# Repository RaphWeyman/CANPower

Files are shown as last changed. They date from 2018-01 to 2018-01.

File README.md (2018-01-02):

# CANPower
Accessory power controller for BMW CAN bus bikes

Two channel power switch using BMW CAN bus messages to control switch output.
Microchip PIC24 based.

Hardware is a printed circuit board created and modifiable with KiCAD. If no modifications are required then the gerbers zip file
can be used as is to get manufactured. The gerber file names are as required by Elecrow.

The software is packaged as a Microchip PIC IDE project and requires Microchip MPLAB X with the 16 bit PIC compiler installed - all free
from the Microchip website.

The 6 way "debug" header on the PCB connects directly to the the Microchip PICKit 3 debugger/programmer. This or some other programmer is
required in order to program the software to the Microchip MCU.

Functionality may easily be changed by modifying the application.c file.
Here's what the default application does:-
 * Switch channel 1 is set to go fully on or fully off with the ignition for accessory power
 * (can easily be changed to staying off by changing the CHANNEL_1_ON define).
 * 
 * Channel 0 is controlled by the ASC switch (can be changed with the BUTTON_PRESSED define).
 * Channel 0 has two modes; modulated and unmodulated. Unmodulated behaves like channel 1; fully on
 * or fully off with the ignition.
 * Modulated is PWM controlled for several power levels from fully off to fully on and each of the quarters
 * inbetween (modify at the CHANNEL_0_PWM_SETTING). PWM is slow for heated clothing but can be changed to
 * fast by changing the CHANNEL_0_PWM_MODE.
 * A long press (>20 seconds) of the control button toggles between modulated and unmodulated modes.
 * A short press (<1 second) of the control button while in modulated mode cycles through the modulation levels.
 * Channel 0 mode and modulation level are stored in EEPROM at power off time (immmediately prior to transition to the
 * alarm simulation state)).
 * 
 * An alarm simulation is included after the ignition is turned off (and the POWER_OFF_DELAY has elapsed).
 * During alarm simulation the switch chip is turned off but the LED indicates as if there were an
 * alarm module armed.
 * Alarm simulation continues for the ALARM_SIMULATION_TIME or can be disabled by setting the ALARM_SIMULATION_TIME to zero.
 * A kickstand warning indication is output to the LEDs if the kickstand is deployed while the ignition is on
 * The warning can be disabled by commenting out the KICKSTAND_WARNING define.
 * 
 * Ignition on is determined by CAN messages being received.
 * Fully on state is maintained POWER_OFF_DELAY. If no CAN messages are received for longer than the POWER_OFF_DELAY
 * then channels 0 and 1 are both turned off and the alarm simulation is stated.
 * Power to the CPU is latched using the PORT_POWER hardware control. When either the ignition is on or the PORT_POWER is set to
 * POWER_PORT_ON power is supplied to the CPU. This allows the CPU to maintain power during the POWER_OFF_DELAY
 * and the ALARM_SIMLATION_TIME. At the end of the ALARM_SIMULATION_TIME, the PORT_POWER is set to POWER_PORT_OFF so as to cut
 * power.
 * 
 * Indications are assumed to be for a single bi-colour LED.
 * LED is dimmed according to the ambient light sensor CAN bus message.
 * LED0 fully on indicates channel 0 is in unmodulated mode.
 * LED1 on but with between 1 and 4 inverse blips indicates channel 0 modulated mode and the number of inverse blips indicate
 * the modulation level (4 blips - fully on).
 * LED1 flashes 4 blips when the channel 0 mode is changed.
 * Both LED0 and LED1 fully off indicate either modulated mode with channel 0 output at the fully off level or no power to the CPU.
 * LED0 flashing at 1Hz indicates that the kickstand is extended.
 * LED0 flashing at 4Hz indicates a switch chip fault - recover by ignition off/ignition on.
 * LED1 blips every few seconds for the alarm simulation.
 * Indications can all be changed by modifying the INDICATIONS and CHANNEL_0_INDICATIONS table.
 *
 * Application is a state machine with a single state variable 'state' and a function of type
 * state_function_t for each state.
 * Each state function must implement the actions for state entry and for state maintenance.
 * The current state's function is invoked regularly (once per timer tick).
 * The StateTransition function is used to change state.
 * The state machnine can be extended by adding to BOTH the states_t and the STATE_FUNCTIONS

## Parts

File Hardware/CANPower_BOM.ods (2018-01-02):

Source: | C:/Users/Raph/Documents/KiCad/CANPower/CANPower.sch
Date: | 26/11/2017 18:06:25
Tool: | Eeschema 4.0.7
Component Count: | 62
Ref | Value | Footprint | Manufacturer | Quantity | Vendor | Vendor#
C1 | 20pF | 1206 |  | 2 | Farnell | 1650896
C2 | 20pF | 1206 |  |  | Farnell | 1650896
C3 | 100nF | 1206 |  | 8 | Farnell | 2070498
C4 | 10uF | 1210 |  | 6 | Farnell | 2070524
C5 | 100nF | 1206 |  |  | Farnell | 2070498
C7 | 10uF | 1210 |  |  | Farnell | 2070524
C9 | 10uF | 1210 |  |  | Farnell | 2070524
C10 | 10uF | 1210 |  |  | Farnell | 2070524
C11 | 22nF | 1206 |  | 4 | Farnell | 2070507
C12 | 2u2 | 1210 |  | 3 | Farnell | 2070526
C13 | 2u2 | 1210 |  |  | Farnell | 2070526
C14 | 100nF | 1206 |  |  | Farnell | 2070498
C15 | 100nF | 1206 |  |  | Farnell | 2070498
C16 | 2u2 | 1210 |  |  | Farnell | 2070526
C17 | 10uF | 1210 |  |  | Farnell | 2070524
C18 | 10uF | 1210 |  |  | Farnell | 2070524
C19 | 100nF | 1206 |  |  | Farnell | 2070498
C20 | 100nF | 1206 |  |  | Farnell | 2070498
C21 | 22nF | 1206 |  |  | Farnell | 2070507
C22 | 100nF | 1206 |  |  | Farnell | 2070498
C23 | 22nF | 1206 |  |  | Farnell | 2070507
C24 | 22nF | 1206 |  |  | Farnell | 2070507
C29 | 100nF | 1206 |  |  | Farnell | 2070498
D1 | BAV74LT1G | SOT-23 |  | 1 | Farnell | 2463435
F1 | 2A | 1206 |  | 1 | Farnell | 1841062
J1 | CAN | Solder wires direct
J3 | Debug | 0.1” pitch 6 way pin header
J4 | Power | Solder wires direct
J5 | Output0 | Solder wires direct
J6 | Output1 | Solder wires direct
J7 | BATT | Solder wires direct
J8 | LED | Solder wires direct
L1 | 22uH |  | Coilcraft MSS7341 | 1 | Farnell | 2288672
Q1 | BSS83P | SOT-23 |  | 2 | Farnell | 2432722
Q2 | BSS83P | SOT-23 |  |  | Farnell | 2432722
R1 | 10K | 1206 |  | 2 | Farnell | 2447455
R2 | 1M | 1206 |  | 5 | Farnell | 2447478
R3 | 1M | 1206 |  |  | Farnell | 2447478
R4 | 470K | 1206 |  | 2 | Farnell | 2447519
R5 | 100K | 1206 |  | 4 | Farnell | 2447453
R6 | 52K3 | 1206 |  | 1 | Farnell | 2307751
R7 | 10K | 1206 |  |  | Farnell | 2447455
R8 | 120R | 1206 |  | 1 | Farnell | 2447462
R9 | 100K | 1206 |  |  | Farnell | 2447453
R10 | 100K | 1206 |  |  | Farnell | 2447453
R11 | 1K | 1206 |  | 1 | Farnell | 2447473
R12 | 8K2 | 1206 |  | 2 | Farnell | 2447547
R13 | 100K | 1206 |  |  | Farnell | 2447453
R14 | 8K2 | 1206 |  |  | Farnell | 2447547
R15 | 2K2 | 1206 |  | 1 | Farnell | 2447496
R16 | 150R | 1206 |  | 2 | Farnell | 2447466
R17 | 150R | 1206 |  |  | Farnell | 2447466
R18 | 470K | 1206 |  |  | Farnell | 2447519
R19 | 1M | 1206 |  |  | Farnell | 2447478
R20 | 1M | 1206 |  |  | Farnell | 2447478
R21 | 1M | 1206 |  |  | Farnell | 2447478
U1 | MCP1727-3302 | SOIC-8 | Microchip | 1 | Farnell | 1331497
U2 | MCP16311 | MSOP-8 | Microchip | 1 | Farnell | 2414134
U3 | MCP2562-E/SN | SOIC-8 | Microchip | 1 | Farnell | 2362839
U4 | MC06XSD200 |  | NXP | 1 | Farnell | 2377190
U5 | PIC24HJ128GP504 | TQFP-44 | Microchip | 1 | Farnell | 1576883
Y1 | 4MHz | HC49 | Fox HC49SDLF | 1 | Farnell | 2063966

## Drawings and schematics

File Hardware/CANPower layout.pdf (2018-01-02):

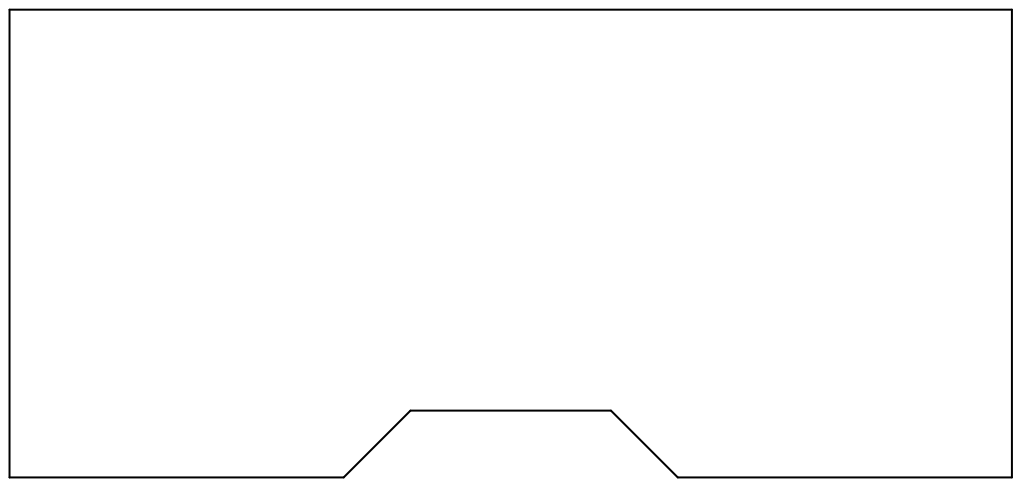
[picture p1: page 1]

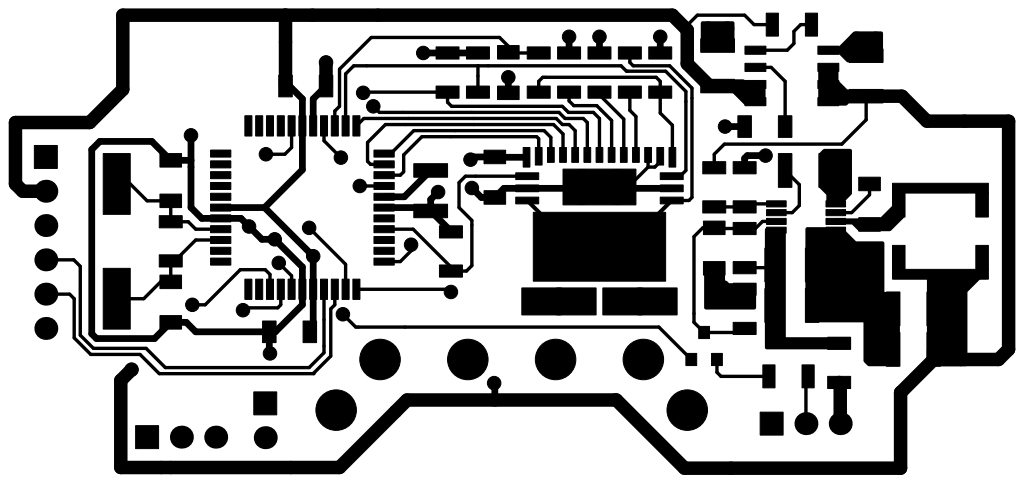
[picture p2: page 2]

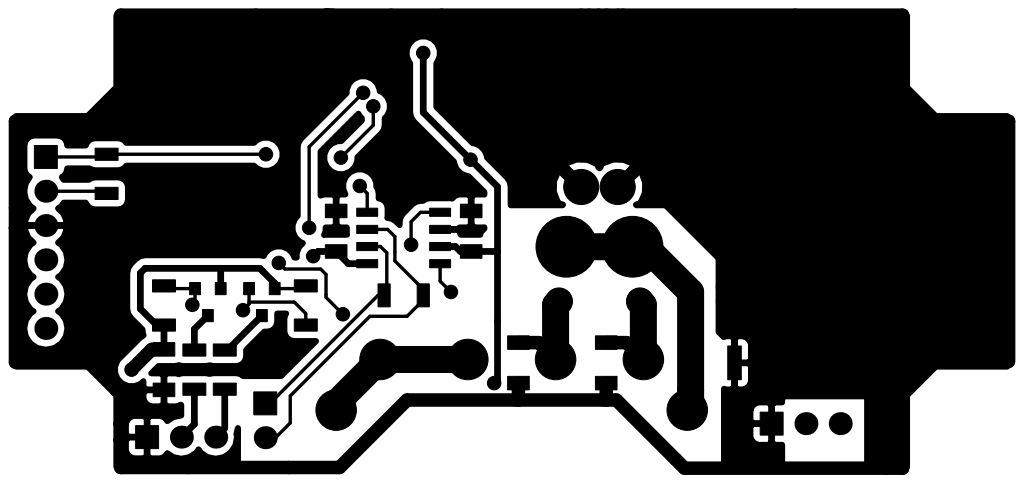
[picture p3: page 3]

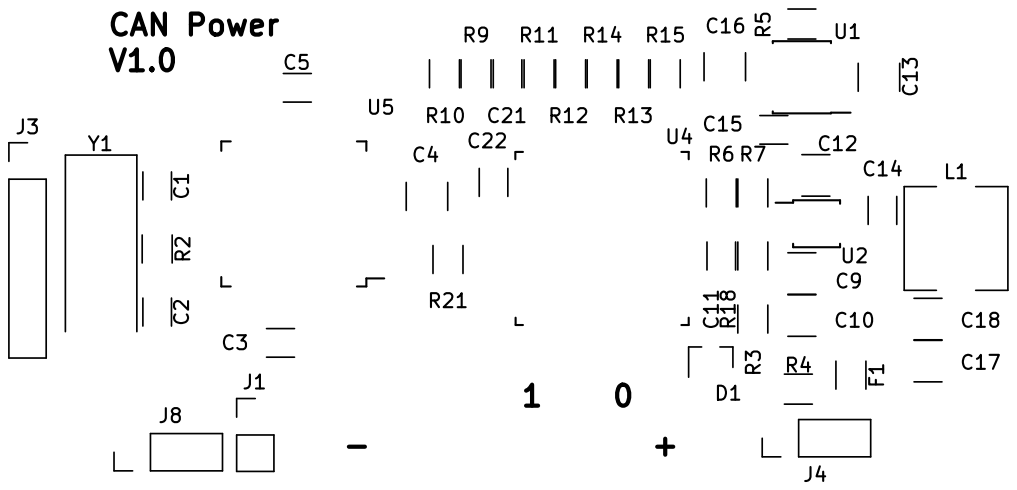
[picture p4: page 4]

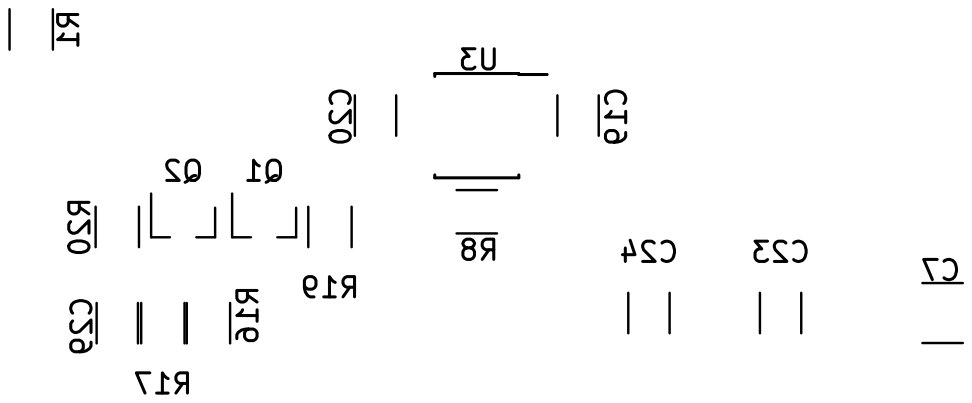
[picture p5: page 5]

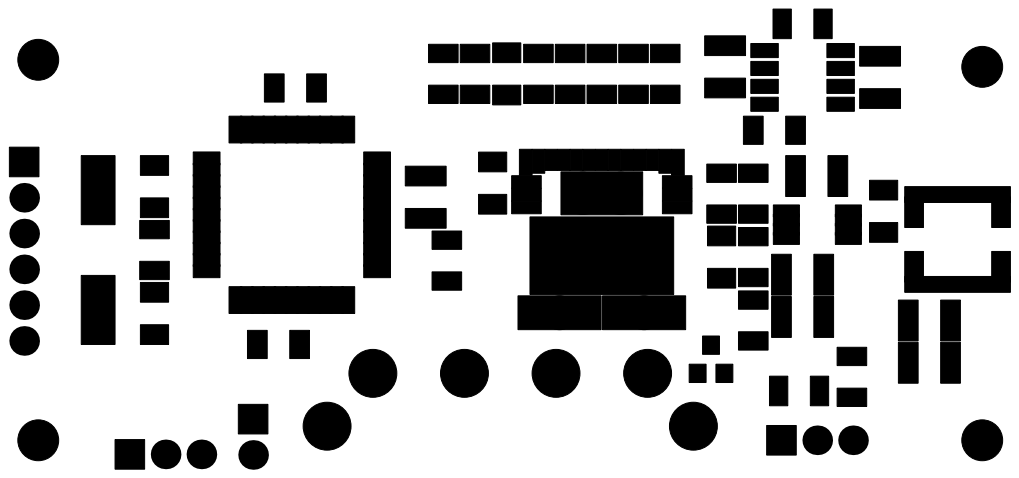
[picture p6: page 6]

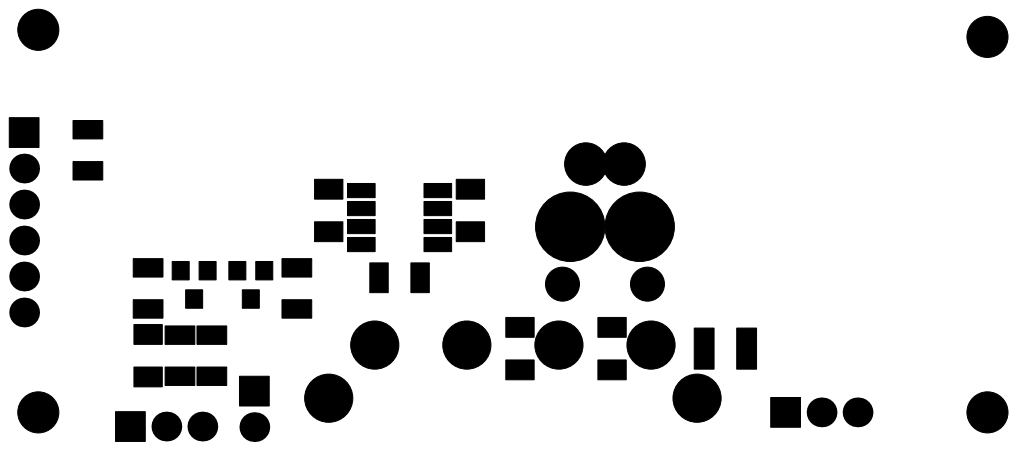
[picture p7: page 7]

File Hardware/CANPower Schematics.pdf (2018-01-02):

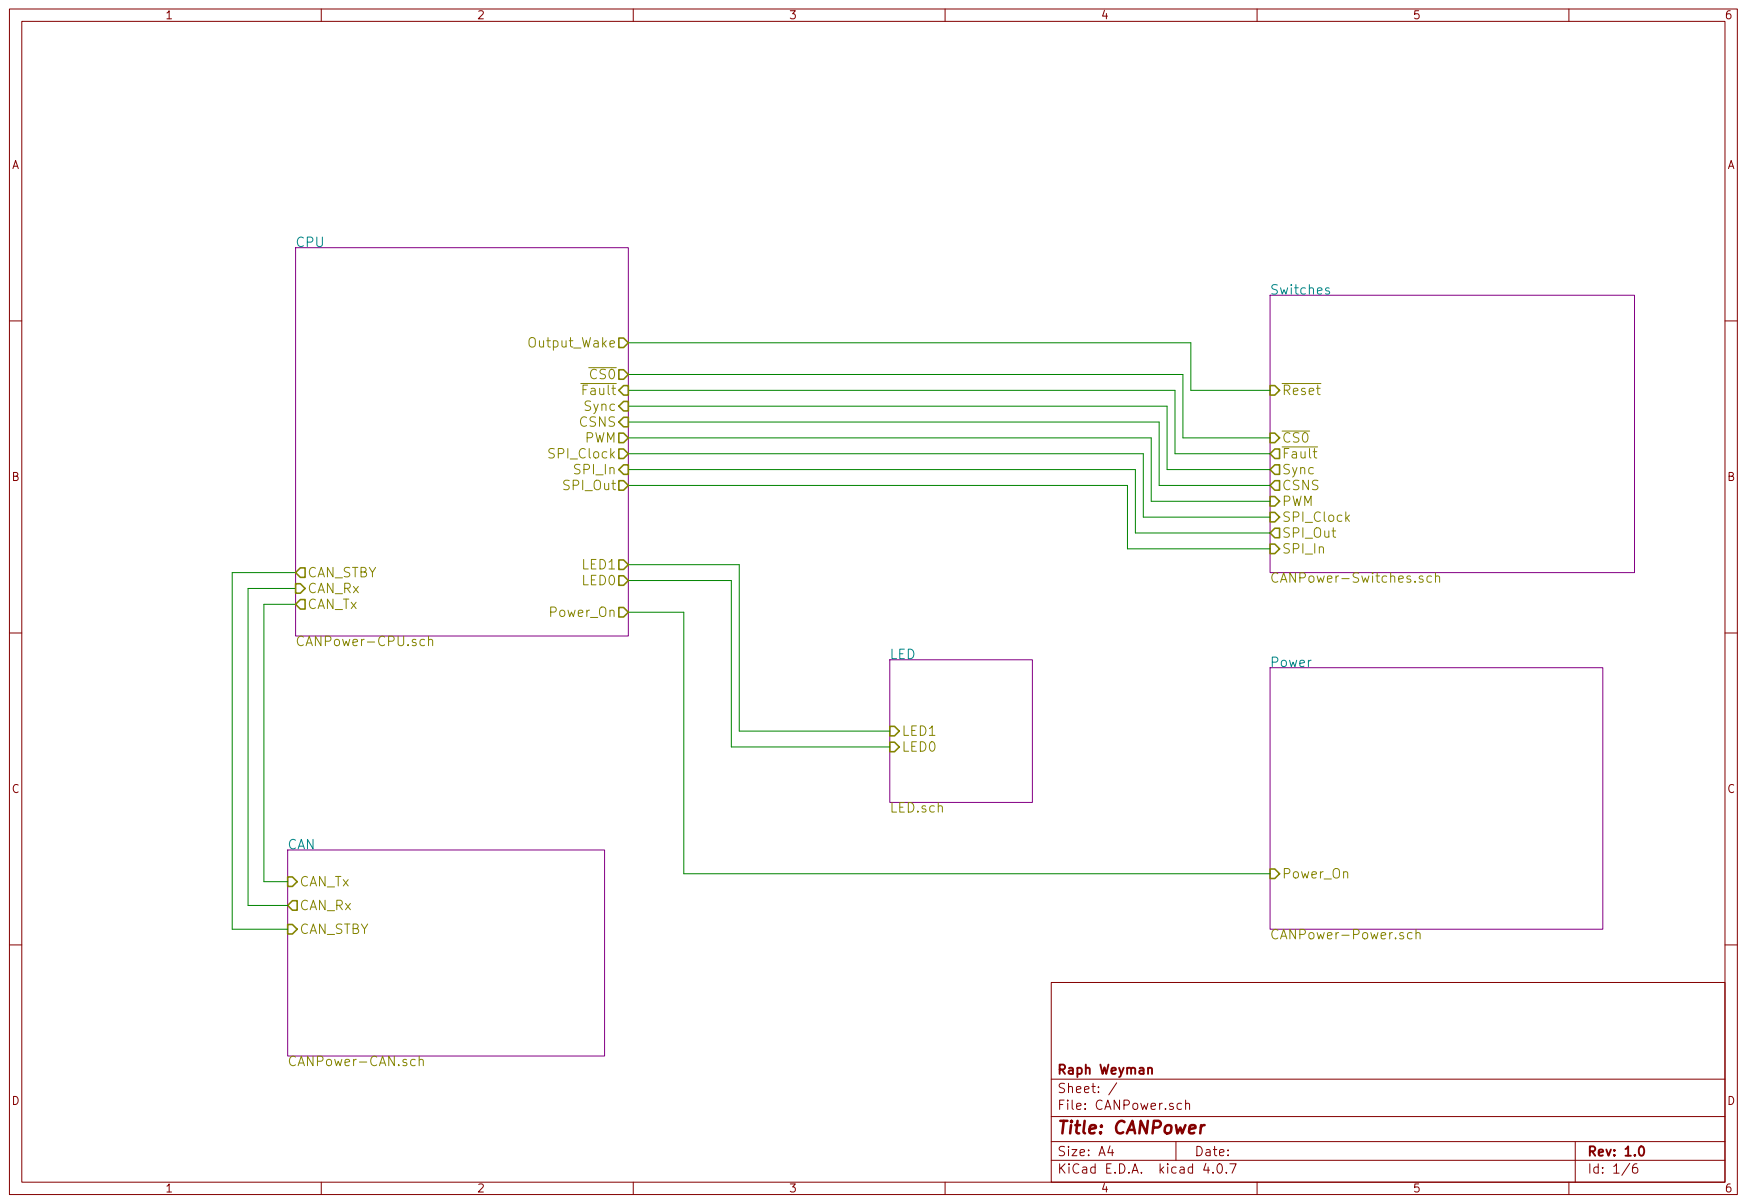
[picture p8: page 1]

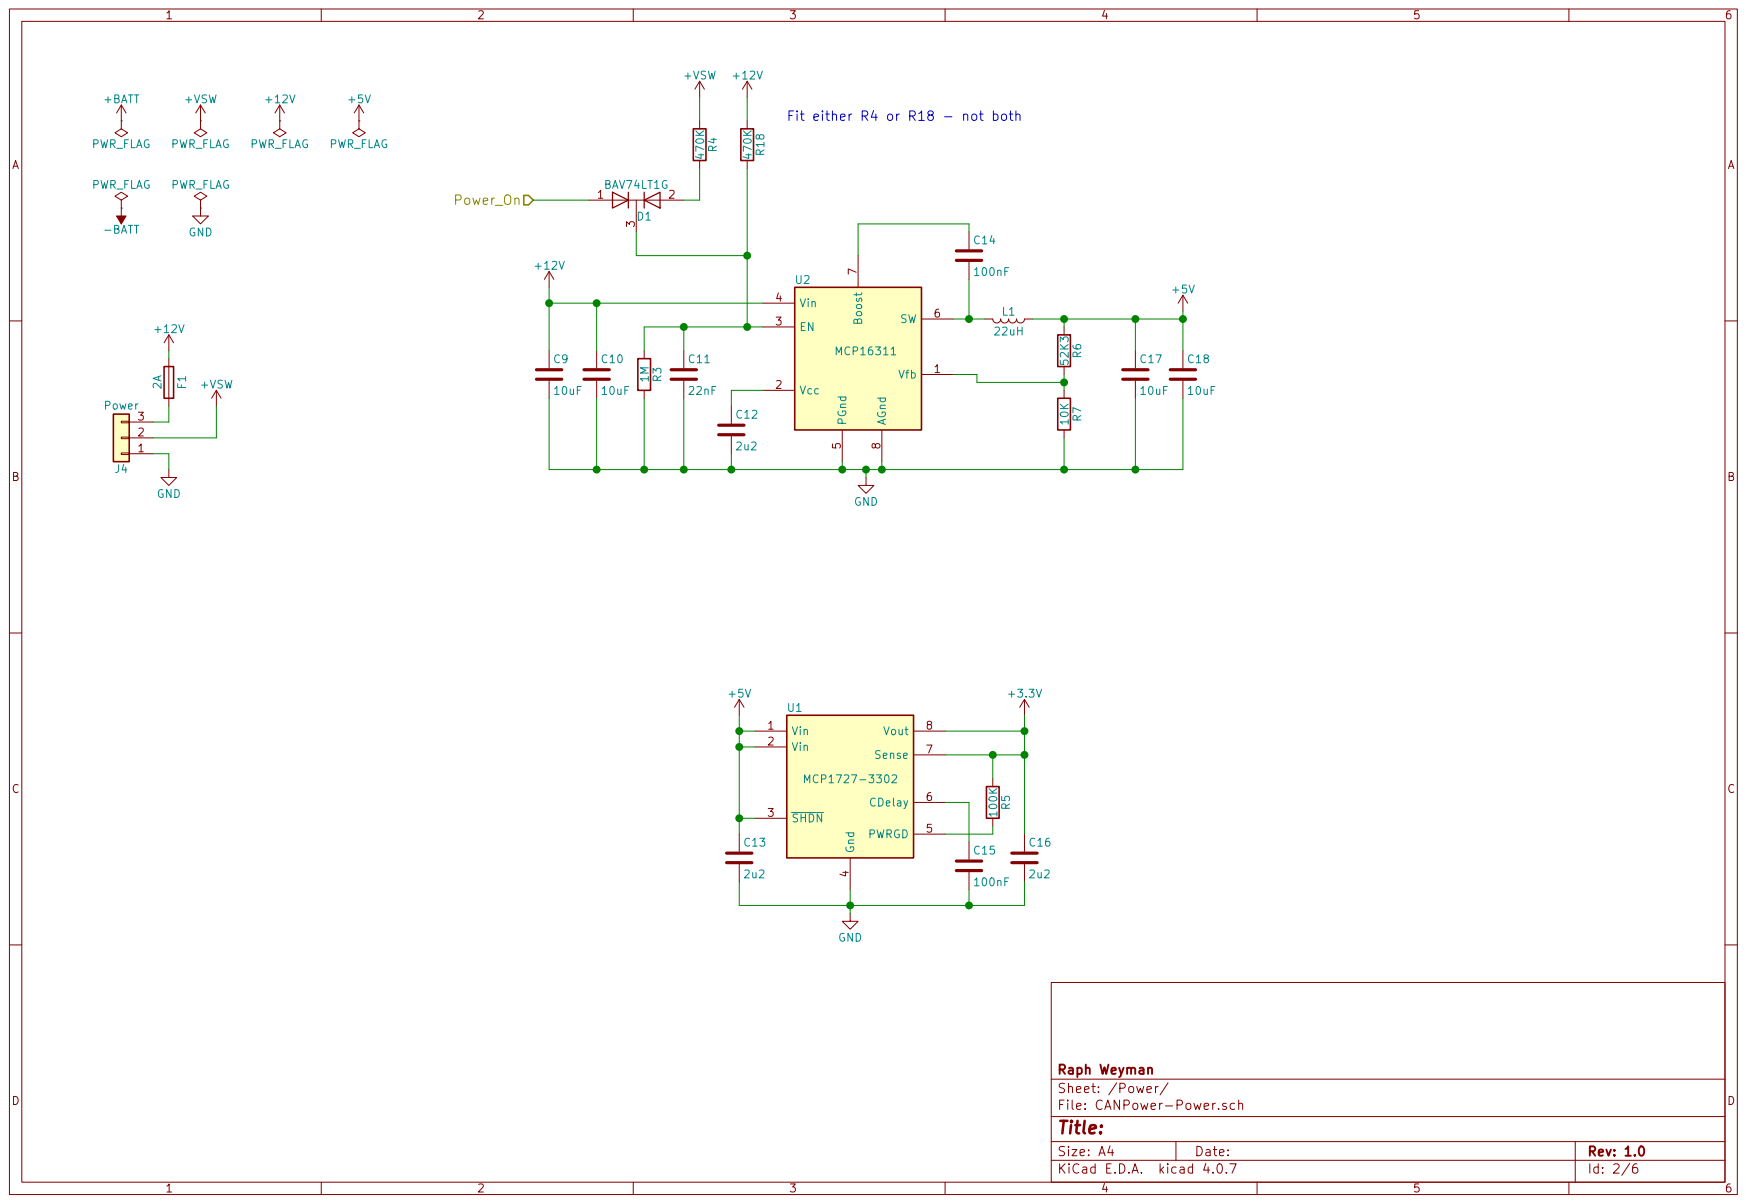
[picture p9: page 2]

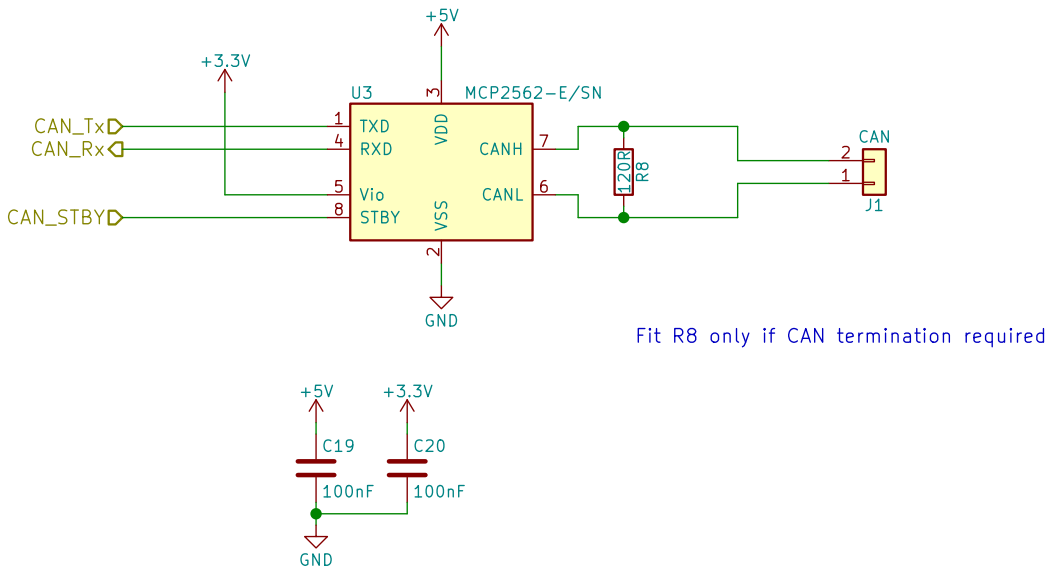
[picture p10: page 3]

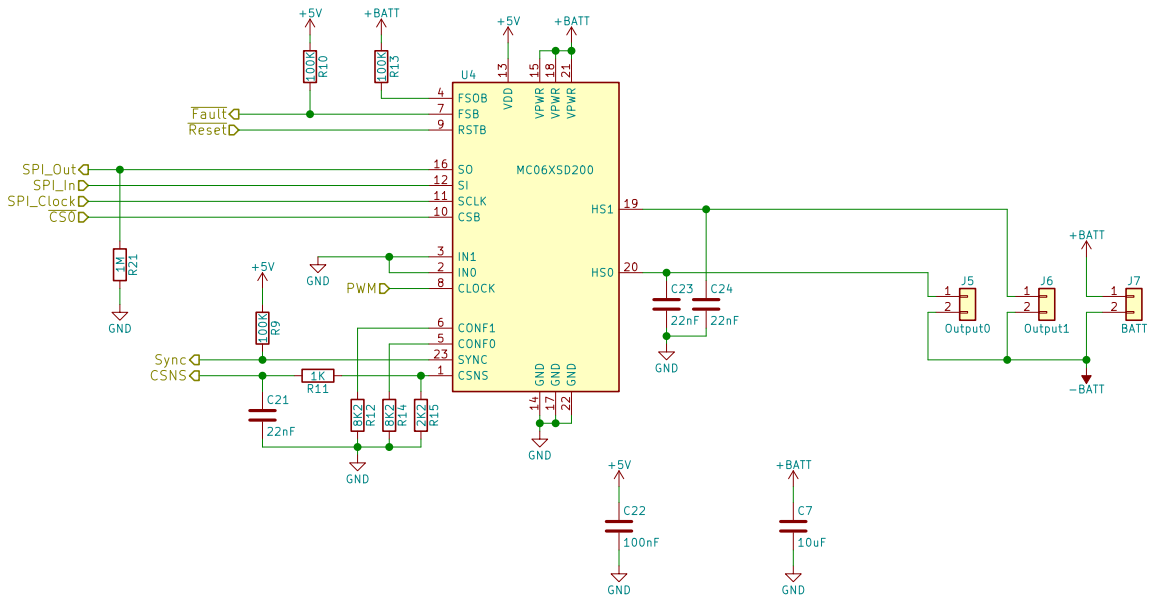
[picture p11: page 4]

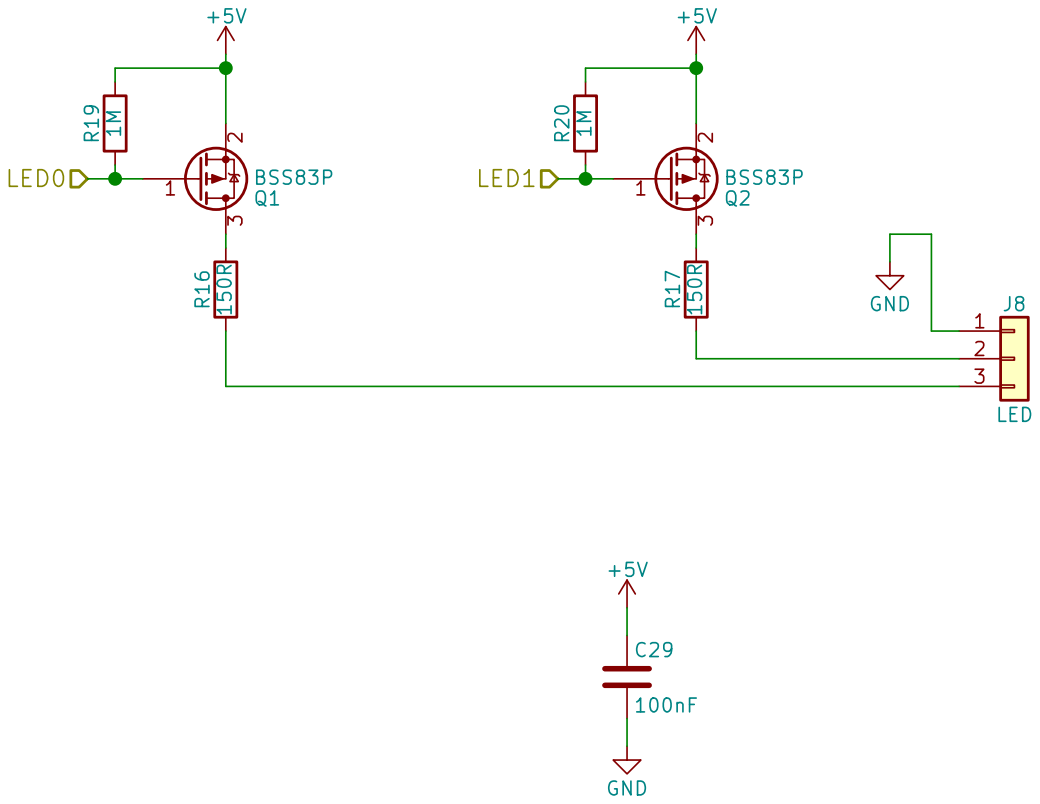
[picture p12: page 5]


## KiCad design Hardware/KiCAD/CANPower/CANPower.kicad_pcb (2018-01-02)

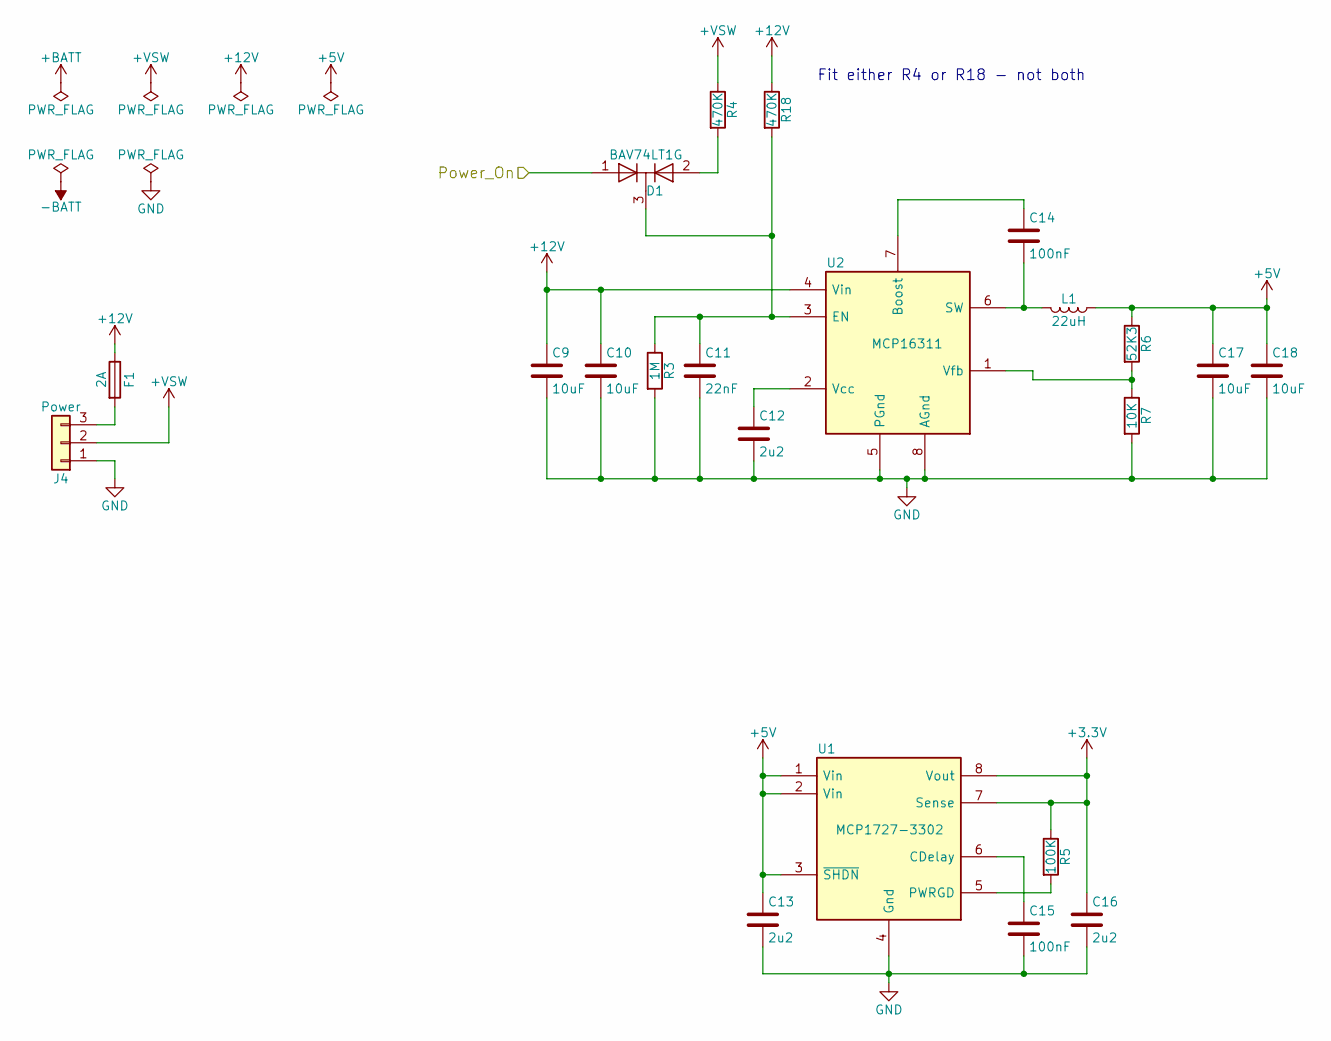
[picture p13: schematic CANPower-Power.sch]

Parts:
C9, C10, C17, C18: 10uF; C_1210
C11: 22nF; C_1206
C12, C13, C16: 2u2; C_1210
C14, C15: 100nF; C_1206
D1: BAV74LT1G; SOT-23
F1: 2A; R_1206
J4: Power; Pin_Header_Straight_1x03_Pitch2.54mm
L1: 22uH; Coilcraft_MSS7341
R3: 1M; R_1206
R4, R18: 470K; R_1206
R5: 100K; R_1206
R6: 52K3; R_1206
R7: 10K; R_1206
U1: MCP1727-3302; SOIC-8_3.9x4.9mm_Pitch1.27mm
U2: MCP16311; MSOP-8_3x3mm_Pitch0.65mm

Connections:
+3V3: C16.1, R5.1, U1.7 (Sense), U1.8 (Vout); also elsewhere on the board
+5V: C13.1, C17.1, C18.1, L1.1, R6.1, U1.1 (Vin), U1.2 (Vin), U1.3 (~SHDN~); also elsewhere on the board
+12V: C9.1, C10.1, F1.1, R18.1, U2.4 (Vin)
+VSW: J4.2, R4.1
/CPU/Power_On: D1.1 (A); also elsewhere on the board
GND: C9.2, C10.2, C11.2, C12.2, C13.2, C15.2, C16.2, C17.2, C18.2, J4.1, R3.2, R7.2, U1.4 (Gnd), U2.5 (PGnd), U2.8 (AGnd); also elsewhere on the board
unnamed: C11.1, D1.3 (K), R3.1, R18.2, U2.3 (EN)
unnamed: C12.1, U2.2 (Vcc)
unnamed: C14.1, U2.7 (Boost)
unnamed: C14.2, L1.2, U2.6 (SW)
unnamed: C15.1, U1.6 (CDelay)
unnamed: D1.2 (A), R4.2
unnamed: F1.2, J4.3
unnamed: R5.2, U1.5 (PWRGD)
unnamed: R6.2, R7.1, U2.1 (Vfb)

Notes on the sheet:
Fit either R4 or R18 - not both

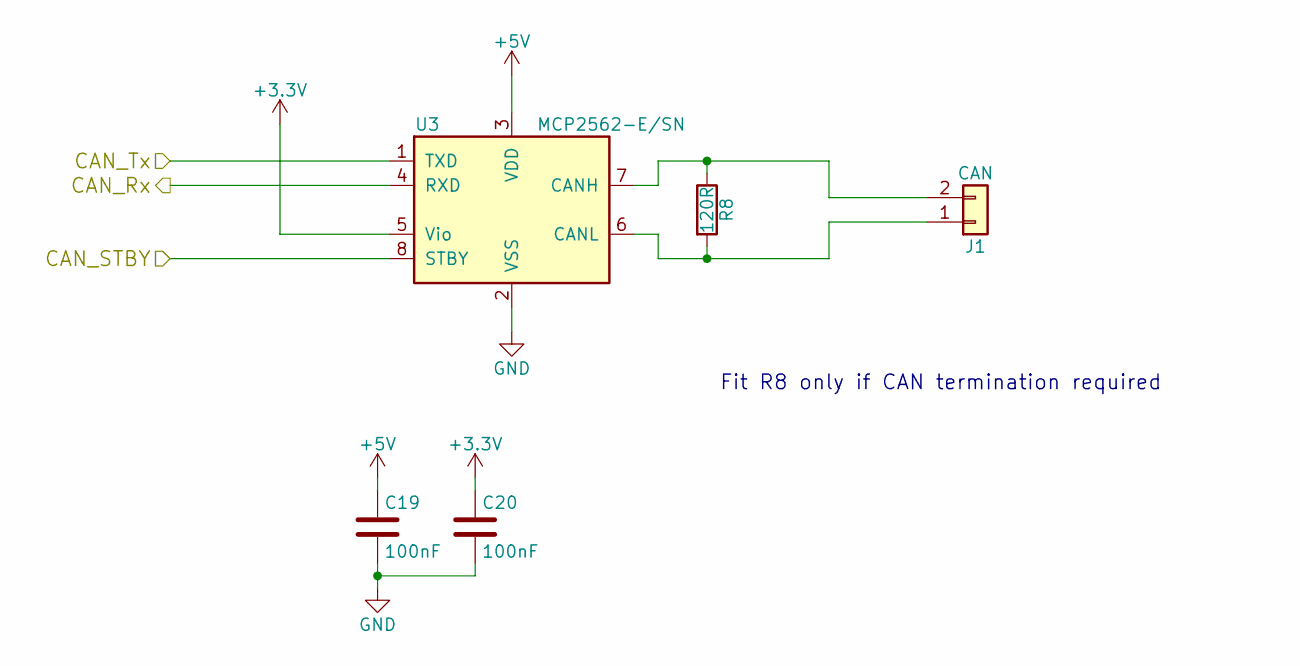
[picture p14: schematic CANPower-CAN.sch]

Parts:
C19, C20: 100nF; C_1206
J1: CAN; Pin_Header_Straight_1x02_Pitch2.54mm
R8: 120R; R_1206
U3: MCP2562-E/SN; SOIC-8_3.9x4.9mm_Pitch1.27mm

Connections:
+3V3: C20.1, U3.5 (Vio); also elsewhere on the board
+5V: C19.1, U3.3 (VDD); also elsewhere on the board
/CAN/CAN_Rx: U3.4 (RXD); also elsewhere on the board
/CAN/CAN_STBY: U3.8 (STBY); also elsewhere on the board
/CAN/CAN_Tx: U3.1 (TXD); also elsewhere on the board
GND: C19.2, C20.2, U3.2 (VSS); also elsewhere on the board
unnamed: J1.1, R8.2, U3.6 (CANL)
unnamed: J1.2, R8.1, U3.7 (CANH)

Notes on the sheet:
Fit R8 only if CAN termination required

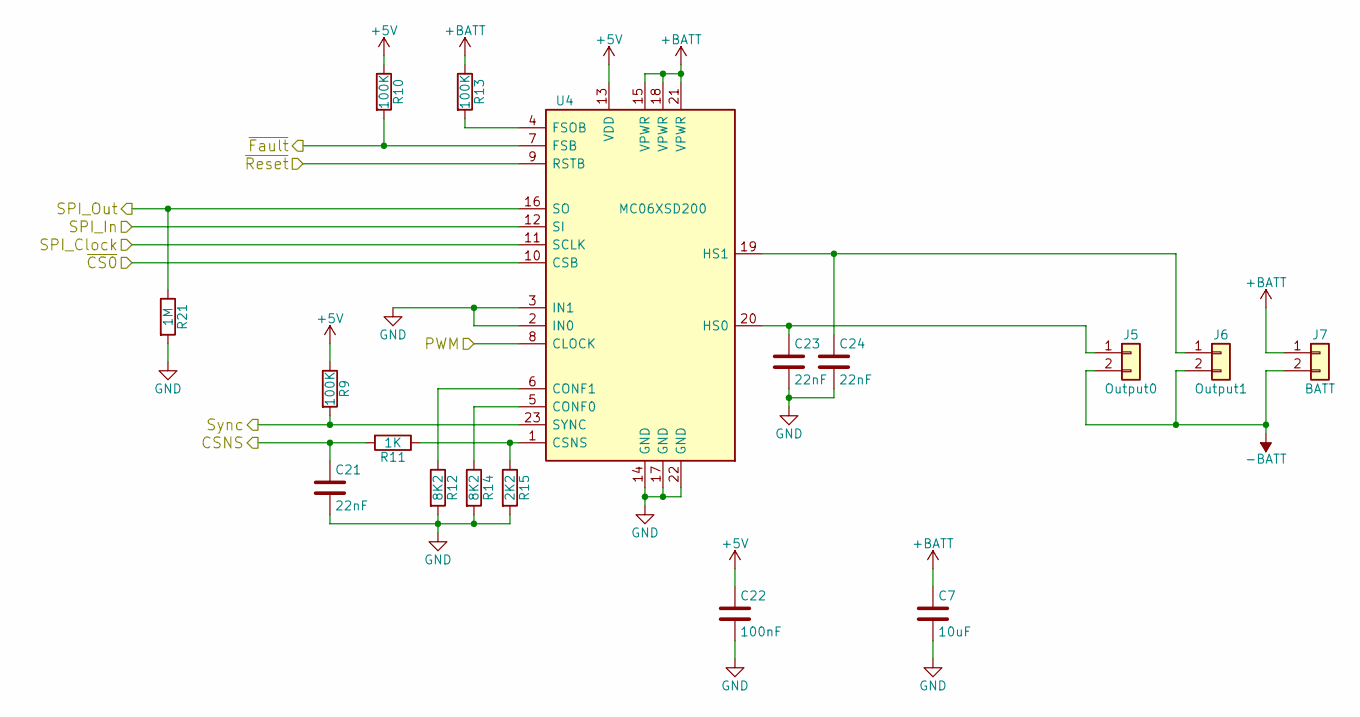
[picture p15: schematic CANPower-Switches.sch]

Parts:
C7: 10uF; C_1210
C21, C23, C24: 22nF; C_1206
C22: 100nF; C_1206
J5: Output0; WireConnection_1.50mmDrill
J6: Output1; WireConnection_1.50mmDrill
J7: BATT; WireConnection_1.50mmDrill
R9, R10, R13: 100K; R_1206
R11: 1K; R_1206
R12, R14: 8K2; R_1206
R15: 2K2; R_1206
R21: 1M; R_1206
U4: MC06XSD200; QFN-23_12x12mm_Pitch0.9mm_holes

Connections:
+5V: C22.1, R9.1, R10.1, U4.13 (VDD); also elsewhere on the board
+BATT: C7.1, J7.1, R13.1, U4.15 (VPWR), U4.18 (VPWR), U4.21 (VPWR)
-BATT: J5.2, J6.2, J7.2
/CPU/CSNS: C21.1, R11.2; also elsewhere on the board
/CPU/Output_Wake: U4.9 (RSTB); also elsewhere on the board
/CPU/PWM: U4.8 (CLOCK); also elsewhere on the board
/CPU/SPI_Clock: U4.11 (SCLK); also elsewhere on the board
/CPU/SPI_In: R21.1, U4.16 (SO); also elsewhere on the board
/CPU/Sync: R9.2, U4.23 (SYNC); also elsewhere on the board
/CPU/~CS0~: U4.10 (CSB); also elsewhere on the board
/CPU/~Fault~: R10.2, U4.7 (FSB); also elsewhere on the board
/Switches/SPI_In: U4.12 (SI); also elsewhere on the board
GND: C7.2, C21.2, C22.2, C23.2, C24.2, R12.2, R14.2, R15.2, R21.2, U4.2 (IN0), U4.3 (IN1), U4.14 (GND), U4.17 (GND), U4.22 (GND); also elsewhere on the board
unnamed: C23.1, J5.1, U4.20 (HS0)
unnamed: C24.1, J6.1, U4.19 (HS1)
unnamed: R11.1, R15.1, U4.1 (CSNS)
unnamed: R12.1, U4.6 (CONF1)
unnamed: R13.2, U4.4 (FSOB)
unnamed: R14.1, U4.5 (CONF0)

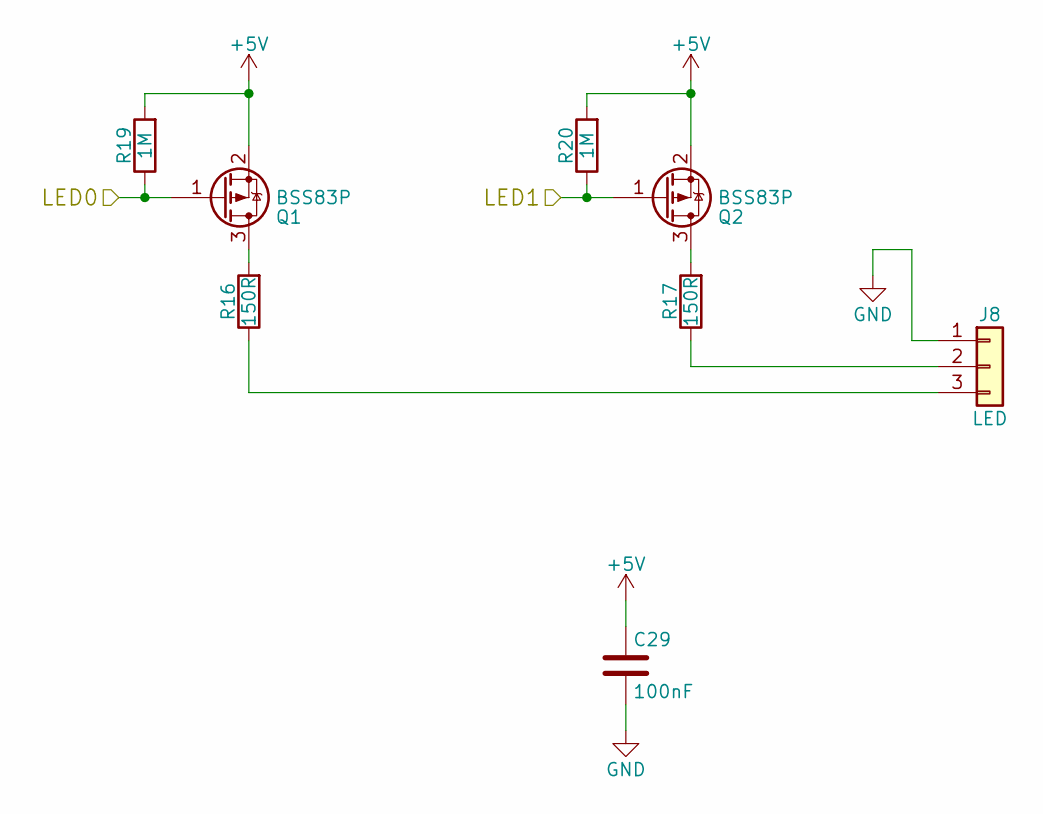
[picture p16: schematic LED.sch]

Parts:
C29: 100nF; C_1206
J8: LED; Pin_Header_Straight_1x03_Pitch2.54mm
Q1, Q2: BSS83P; SOT-23
R16, R17: 150R; R_1206
R19, R20: 1M; R_1206

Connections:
+5V: C29.1, Q1.2 (S), Q2.2 (S), R19.2, R20.2; also elsewhere on the board
/CPU/LED0: Q1.1 (G), R19.1; also elsewhere on the board
/CPU/LED1: Q2.1 (G), R20.1; also elsewhere on the board
GND: C29.2, J8.1; also elsewhere on the board
unnamed: J8.2, R17.1
unnamed: J8.3, R16.1
unnamed: Q1.3 (D), R16.2
unnamed: Q2.3 (D), R17.2

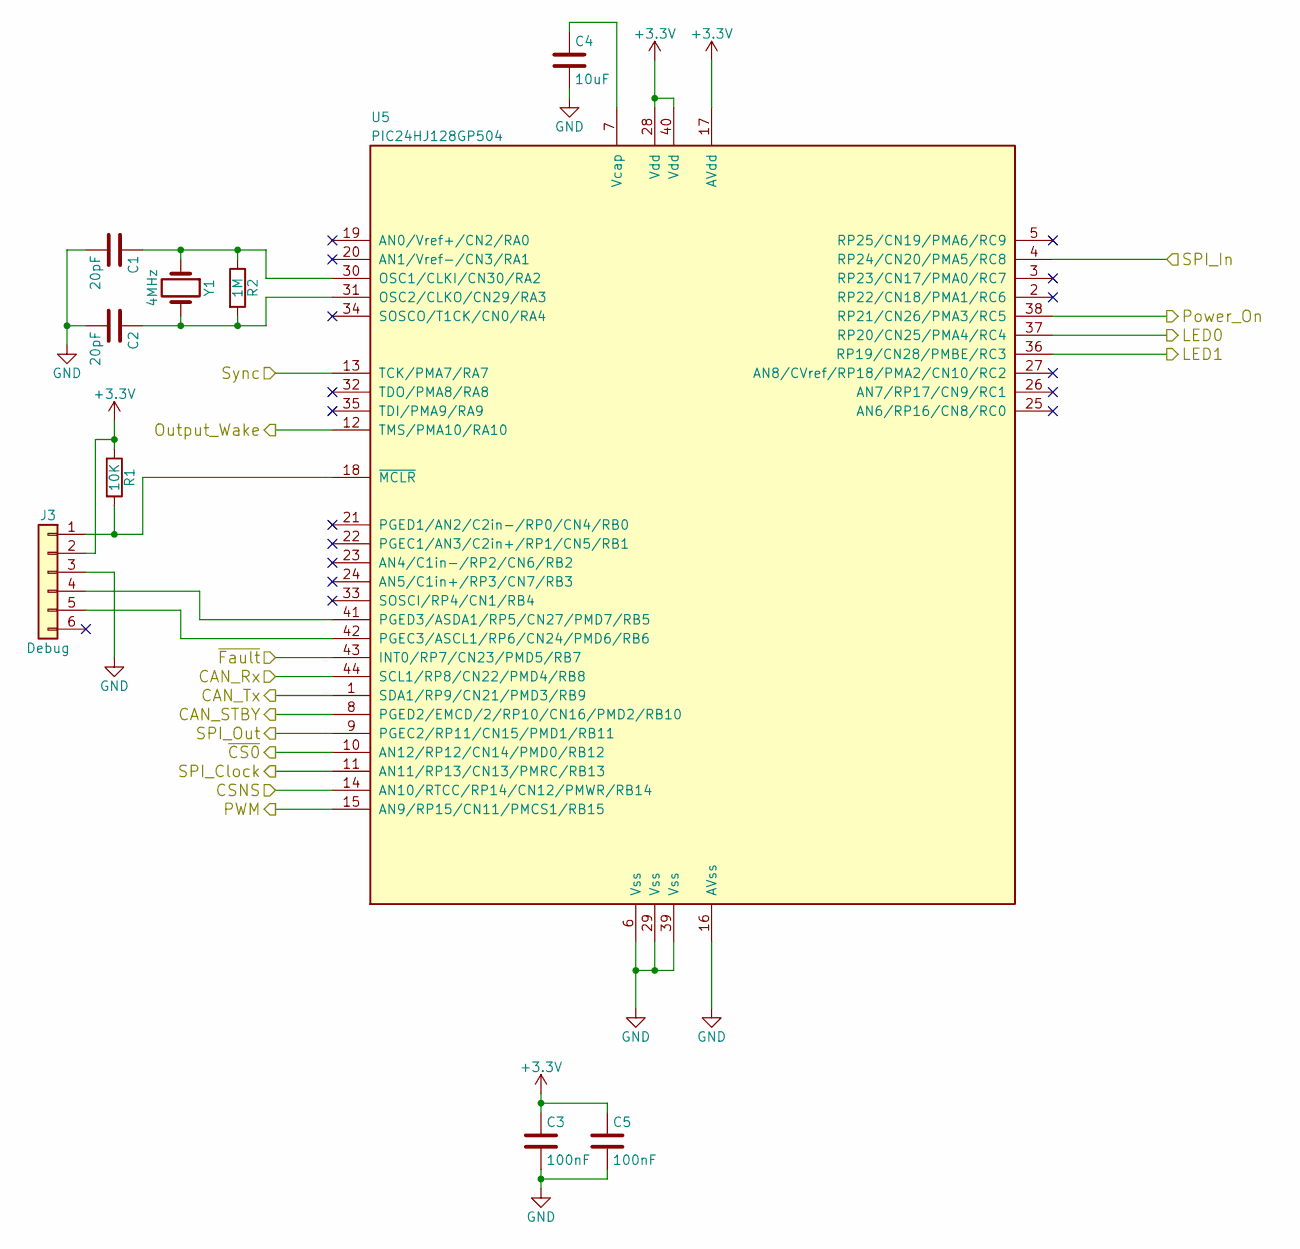
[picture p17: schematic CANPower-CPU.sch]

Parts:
C1, C2: 20pF; C_1206
C3, C5: 100nF; C_1206
C4: 10uF; C_1210
J3: Debug; Pin_Header_Straight_1x06_Pitch2.54mm
R1: 10K; R_1206
R2: 1M; R_1206
U5: PIC24HJ128GP504; PQFP-44_10x10mm_Pitch0.8mm
Y1: 4MHz; Crystal_SMD_HC49-SD

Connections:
+3V3: C3.1, C5.1, J3.2, R1.1, U5.17 (AVdd), U5.28 (Vdd), U5.40 (Vdd); also elsewhere on the board
/CAN/CAN_Rx: U5.44 (SCL1/RP8/CN22/PMD4/RB8); also elsewhere on the board
/CAN/CAN_STBY: U5.8 (PGED2/EMCD/2/RP10/CN16/PMD2/RB10); also elsewhere on the board
/CAN/CAN_Tx: U5.1 (SDA1/RP9/CN21/PMD3/RB9); also elsewhere on the board
/CPU/CSNS: U5.14 (AN10/RTCC/RP14/CN12/PMWR/RB14); also elsewhere on the board
/CPU/LED0: U5.37 (RP20/CN25/PMA4/RC4); also elsewhere on the board
/CPU/LED1: U5.36 (RP19/CN28/PMBE/RC3); also elsewhere on the board
/CPU/Output_Wake: U5.12 (TMS/PMA10/RA10); also elsewhere on the board
/CPU/PWM: U5.15 (AN9/RP15/CN11/PMCS1/RB15); also elsewhere on the board
/CPU/Power_On: U5.38 (RP21/CN26/PMA3/RC5); also elsewhere on the board
/CPU/SPI_Clock: U5.11 (AN11/RP13/CN13/PMRC/RB13); also elsewhere on the board
/CPU/SPI_In: U5.4 (RP24/CN20/PMA5/RC8); also elsewhere on the board
/CPU/Sync: U5.13 (TCK/PMA7/RA7); also elsewhere on the board
/CPU/~CS0~: U5.10 (AN12/RP12/CN14/PMD0/RB12); also elsewhere on the board
/CPU/~Fault~: U5.43 (INT0/RP7/CN23/PMD5/RB7); also elsewhere on the board
/Switches/SPI_In: U5.9 (PGEC2/RP11/CN15/PMD1/RB11); also elsewhere on the board
GND: C1.2, C2.2, C3.2, C4.2, C5.2, J3.3, U5.6 (Vss), U5.16 (AVss), U5.29 (Vss), U5.39 (Vss); also elsewhere on the board
unnamed: C1.1, R2.1, U5.30 (OSC1/CLKI/CN30/RA2), Y1.1
unnamed: C2.1, R2.2, U5.31 (OSC2/CLKO/CN29/RA3), Y1.2
unnamed: C4.1, U5.7 (Vcap)
unnamed: J3.1, R1.2, U5.18 (~MCLR~)
unnamed: J3.4, U5.41 (PGED3/ASDA1/RP5/CN27/PMD7/RB5)
unnamed: J3.5, U5.42 (PGEC3/ASCL1/RP6/CN24/PMD6/RB6)

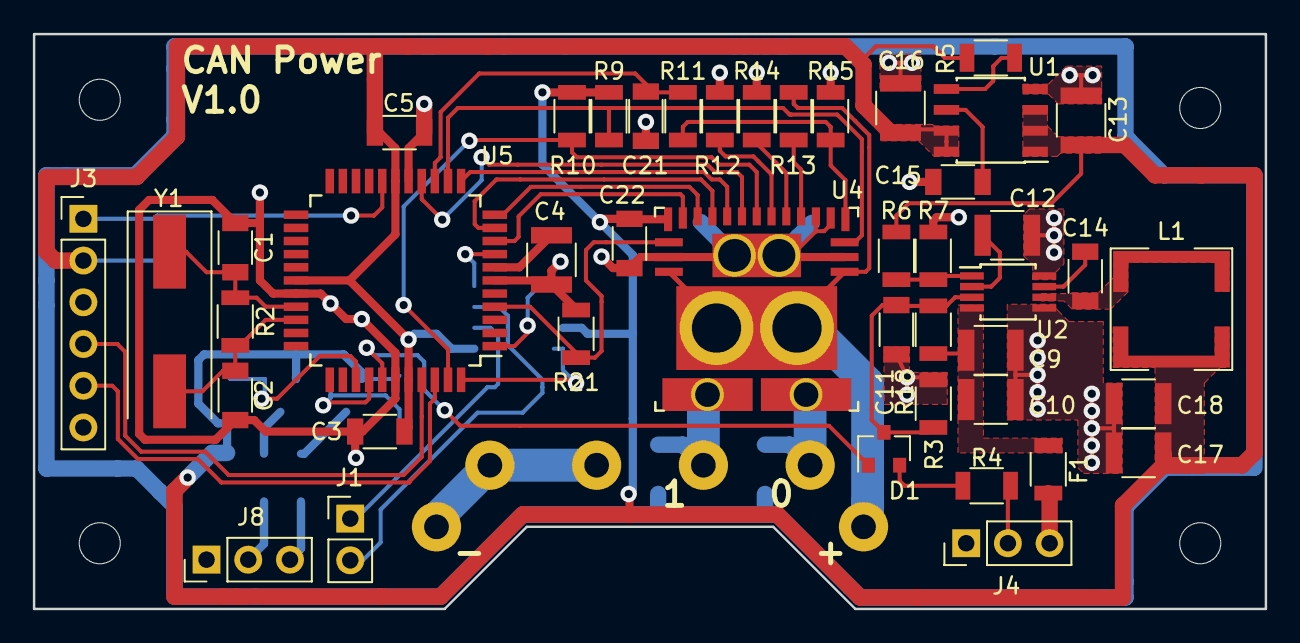
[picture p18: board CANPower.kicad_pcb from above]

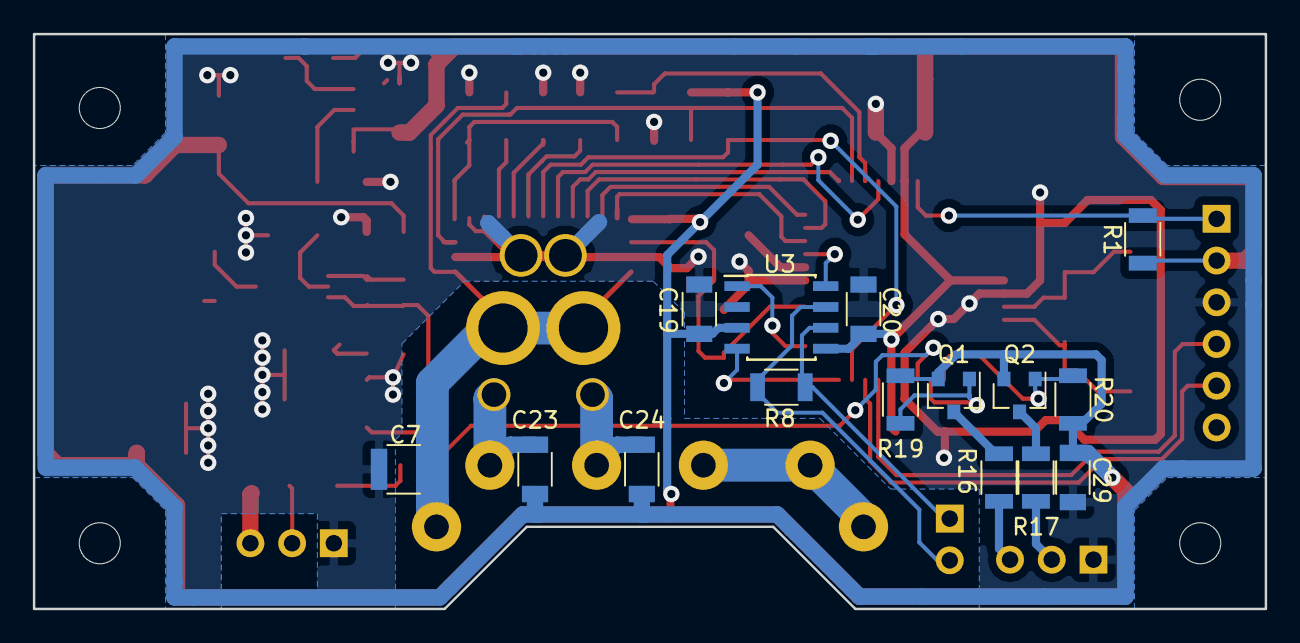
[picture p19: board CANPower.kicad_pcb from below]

Board: 2 copper layers, 75.0 x 35.0 mm, 62 parts (15 on the bottom side), 49 nets.

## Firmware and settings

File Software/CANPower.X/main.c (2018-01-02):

/*
 * File:   main.c
 * Author: Raph Weyman
 *
 * Created on 03 November 2017, 10:05
 *
 * Basic principle is to execute the Initialisation functions for each module
 * and then repeatedly invoke the Tasks function of each module. However, between each
 * Task invocation the processor will idle - to be woken up by an interrupt. So at least
 * one regular interrupt source must have been set up during module initialisation.
 * Tasks are invoked once per timer tick. Wake-ups for interrupts other than the timer
 * are ignored for the purposes of processing the Tasks.
 */

#include <stdlib.h>
#include <stdbool.h>
#include "xc.h"
#include "ports.h"
#include "timer.h"
#include "LEDs.h"
#include "SPI.h"
#include "CAN.h"
#include "hardware.h"
#include "MC06XSD200.h"
#include "EEPROM.h"
#include "application.h"


// *****************************************************************************
// *****************************************************************************
// ** Initialize
// ** Invoked once at started - calls each module's initialisation
// *****************************************************************************
// *****************************************************************************
void Initialize(void)
{
    InitializeHardware();
    InitializePorts();
    InitializeEEPROM(); // after the hardware but before starting the timer - it could take a while
    InitializeTimer();
    InitializeLEDs();
    InitializeSPI();
    InitializeCAN();
    InitializeMC06XSD200();
    InitializeApplication();
}


// *****************************************************************************
// *****************************************************************************
// ** Tasks
// ** Invoked once per timer tick during normal execution.
// ** Calls each module's tasks function round-robin. Task functions are expected
// ** to return quickly for co-operative multi-tasking.
// *****************************************************************************
// *****************************************************************************
void Tasks(void)
{
    ApplicationTasks();
    LEDTasks();
    MC06XSD200Tasks();
}


// *****************************************************************************
// *****************************************************************************
// Section: Main Entry Point
// *****************************************************************************
// *****************************************************************************

int main(void)
{
    uint16_t last_time, now;
    Initialize();

    // tasks invoked once per timer tick. I.e. when the timer value changes
    last_time = Timer();
    while (true)
    {
        now = Timer();
        if (now != last_time)
        {
            last_time = now;
            Tasks();            
        }
        // watchdog time out is 64ms. Idling resets it. Must be here at least every 64ms
        Idle();
    }

    /* Execution should not come here during normal operation */

    return (EXIT_FAILURE);
}


/*******************************************************************************
 End of File
*/

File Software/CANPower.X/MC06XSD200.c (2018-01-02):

/* 
 * File:   MC06XSD200.c
 * Author: Raph Weyman
 *
 * Created on 13 November 2017, 18:46
 * 
 * Driver for the NXP MC06XSD200 dual power switch.
 * Driven via the SPI. Expansion port might have another switch on
 * it but this driver only works for the onboard switch which is
 * gated by CS0.
 * 
 * After SwitchChipOn, output PWM levels from 0 (off) to 256 (fully on) can be set
 * for each of the two output channels.
 *
 * Any chip configuration failure or fault condition on either channel causes the entire switch to be turned off. I.e. a fault on
 * either channel will turn off both channels.
 * SwitchFault will then return true. The SwitchChipOn can then be re-invoked.
 *
 * PWM clock is generated from timer 3 and output compare 1
 * PWM clock frequency is 15KHz for a switch output PWM frequency of 59Hz.
 *
 * Each channel can be run in SLOW_PWM or FAST_PWM mode. FAST_PWM is hardware controlled output at
 * the PWM frequency.
 * SLOW_PWM is software controlled. The hardware PWM output is either fully on or fully off but cycled slowly
 * under software control over 256 timer ticks (2.56 seconds at 10ms timer ticks).
 * 
 * SPI and ports and the system timer must have been initialised prior to
 * initialising this module.
 */

#include "MC06XSD200.h"
#include "ports.h"
#include "SPI.h"
#include "hardware.h"
#include "xc.h"

// hardware PWM clock
#define PWM_PERIOD 66 // uS - 15KHz

// requested PWM output levels 0-255
static uint16_t PWM_level_0;
static PWM_mode_t PWM_mode_0;
static uint16_t PWM_level_1;
static PWM_mode_t PWM_mode_1;


// counts up once per MC06XSD200Tasks invocation (assumed to be invoked every timer tick)
// for the software SLOW_PWM mode
static uint8_t software_PWM_counter;


// the state machine
typedef enum
{
    OFF=0, // held in reset
    STARTING0, // about to turn on - state only here to ensure that reset is held long enough in all circumstances
    STARTING1,
    ON, // OUTPUT_WAKE line high - chip just out of reset initialisation not started
    INITIALIZING, // initialisation sequence sent to SPI
    READY, // initialised and ready to have the output state written etc.
    READBACK, // status being read
    PROGRAMMING, // output state being updated
    FAULT // fault condition detected. Switch held in reset
}states_t;
static states_t state;


#define WATCHDOG 0x8000 // SPI command watchdog bit must be toggled regularly
#define PARITY 0x4000 // SPI parity bit - must be even total number of bits set
#define NORMAL_MODE 0x0200 // Normal mode indicated in readback when set

// register configuration values
// each has a value to configure, a mask for the read back checking, and a value for the read back checking
#define GCR_INITIAL_VALUE (0x1810|PARITY) // GCR initial - watchdog disabled, no current sensing, PWM initially disabled
#define GCR_VALUE 0x1980                  // GCR - watchdog enabled, no current sensing, PWM enabled
#define GCR_READBACK_MASK 0x3FFF
#define GCR_READBACK_VALUE (0x1800|NORMAL_MODE|(GCR_VALUE&0x01FF)) 
#define PWM_0_VALUE (0x0400|PARITY)       // PWM_0 - off at level 0
#define PWM_0_READBACK_MASK 0x3E00
#define PWM_0_READBACK_VALUE (0x0800|NORMAL_MODE|(PWM_0_VALUE&0x0000))
#define PWM_1_VALUE (0x2400)              // PWM_1 - off at level 0
#define PWM_1_READBACK_MASK 0x3E00
#define PWM_1_READBACK_VALUE (0x2800|NORMAL_MODE|(PWM_1_VALUE&0x0000))
#define CONFR_0_VALUE (0x08E0)            // CONFR_0 - open load detection disabled, direct control disabled, medium slew
#define CONFR_0_READBACK_MASK 0x3FFF
#define CONFR_0_READBACK_VALUE (0x0C00|NORMAL_MODE|(CONFR_0_VALUE&0x01FF))
#define CONFR_1_VALUE (0x28E0|PARITY)     // CONFR_1 - open load detection disabled, direct control disabled, medium slew
#define CONFR_1_READBACK_MASK 0x3FFF
#define CONFR_1_READBACK_VALUE (0x2C00|NORMAL_MODE|(CONFR_1_VALUE&0x01FF))
#define OCR_0_VALUE (0x1026)              // OCR_0 - external PWM, low current ratios, tOCH1, tOCM1, iOCH2 (23A), iOCM2 (9A), iOCL1 (5A)
#define OCR_0_READBACK_MASK 0x3FFF
#define OCR_0_READBACK_VALUE (0x1000|NORMAL_MODE|(OCR_0_VALUE&0x01FF))
#define OCR_1_VALUE (0x3026|PARITY)       // OCR_1 - external PWM, low current ratios, tOCH1, tOCM1, iOCH2 (23A), iOCM2 (9A), iOCL1 (5A)
#define OCR_1_READBACK_MASK 0x3FFF
#define OCR_1_READBACK_VALUE (0x3000|NORMAL_MODE|(OCR_1_VALUE&0x01FF))
#define RETRYR_0_VALUE (0x1400)           // RETRYR_0 - 16 x 150ms retries 
#define RETRYR_0_READBACK_MASK 0x3FFF
#define RETRYR_0_READBACK_VALUE (0x1400|NORMAL_MODE|(RETRYR_0_VALUE&0x01FF))
#define RETRYR_1_VALUE (0x3400|PARITY)    // RETRYR_1 - 16 x 150ms retries
#define RETRYR_1_READBACK_MASK 0x3FFF
#define RETRYR_1_READBACK_VALUE (0x3400|NORMAL_MODE|(RETRYR_1_VALUE&0x01FF))
// fault and status registers don't have configuration values but are checked after readback
#define STATR_READBACK_MASK 0x3FBC       // any fault condition
#define STATR_READBACK_VALUE (NORMAL_MODE)
#define FAULT_0_READBACK_MASK 0x3F3F     // any fault condition
#define FAULT_0_READBACK_VALUE (0x0400|NORMAL_MODE)
#define FAULT_1_READBACK_MASK 0x3F3F     // any fault condition
#define FAULT_1_READBACK_VALUE (0x2400|NORMAL_MODE)
      
 
// SPI command sequences - maximum SPI_MAX_WORDS each
#define INITIALIZATION_LENGTH 14
static const SPIData_t initialization_sequence[INITIALIZATION_LENGTH] =
{
    GCR_INITIAL_VALUE,
    PWM_0_VALUE,
    PWM_1_VALUE,
    CONFR_0_VALUE,
    CONFR_1_VALUE,
    OCR_0_VALUE,
    OCR_1_VALUE,
    RETRYR_0_VALUE,
    RETRYR_1_VALUE,
    GCR_VALUE,
    // read the fault and status registers so as to clear any initial fault conditions
    0x0001 | PARITY,             // FAULT_0
    0x2001,                      // FAULT_1
    0x0000 ,                     // STATR
    0x0006 | WATCHDOG | PARITY   // dummy GCR read command so that previous value can be read and also a watchdog kick
};

#define READBACK_LENGTH 14
static const SPIData_t readback_sequence[READBACK_LENGTH] =
{
    0x0000 ,                     // STATR
    0x0001 | PARITY,             // FAULT_0
    0x2001,                      // FAULT_1
    0x0002 | PARITY,             // PWMR_0
    0x2002,                      // PWMR_1
    0x0003,                      // CONFR_0
    0x2003 | PARITY,             // CONFR_1
    0x0004 | PARITY,             // OCR_0
    0x2004,                      // OCR_1
    0x0005,                      // RETRYR_0
    0x2005 | PARITY,             // RETRYR_1
    0x0006,                      // GCR
    0x0007 | PARITY,             // DIAGR
    0x0006 | WATCHDOG | PARITY   // dummy GCR read command so that previous value can be read and also a watchdog kick
};

// Register order for the readback
enum {DUMMY=0, STATR, FAULT_0, FAULT_1, PWMR_0, PWMR_1, CONFR_0, CONFR_1, OCR_0, OCR_1, RETRYR_0, RETRYR_1, GCR, DIAGR};

// one to get filled in with the programming commands
#define PROGRAMMING_LENGTH 4
static SPIData_t programming_sequence[PROGRAMMING_LENGTH];
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
